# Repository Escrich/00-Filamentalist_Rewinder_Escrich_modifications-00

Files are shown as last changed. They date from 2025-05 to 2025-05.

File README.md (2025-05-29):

# Filamentalist Rewinder Escrich modifications
ERCF Filamentalist rewinder modifications

<p align="left">
testing prototipes
</p>

### Few days ago (20250524), I discovered the Filamentalist  rewinder

Then I decided to print the first prototype and made some changes, after that, I discovered the latest version of Filamentalist rewinder, then I will come back soon with new modifications!

### Modifications has been done on following elements:

- Modified back roller, now has been made as a single part, ussing supports at printing time, I need to have a look to the new ones (V3), in order to adopt the new ones or continue with those rebuilt old ones,
  I made the change to a single part, because the two threaded halves, doesn't rotate too aligned, at least in my prototipe.
- Changed commercial rubber bands by a TPU 3D printed one, with some lines to deliver better grip and improved reel driving.
- Changes on front Rim rollers, because of the use of the new rubber band, I made a modification, converting the old rim in two halves, with a centering ring inside,
  and four heat inserts, mounted from the opposite face as the screws face, using four units of M3x15 screws,
  to have single segure, well centered part, in next days I will make some changes, in order to have the locking screw, to avoid movements relative to the axis.
- Changes in drive roller in order to avoid the use of O-Rings, again a specially designed TPU ring, has been mounted instead the two O-Rings, because of this modification, I did again,
  a two parts drive roller, it closes using 4 units of M2'5x8 screws, and 4 units of M2'5 heat inserted nuts, as I normally do, the nuts are mounteds in the opposite side of the screws side.
- Changes on filament input output part, because as on lots of DYI designs, there is a screw, working as an axle, with a big part of group of parts rotating around it,
  but scrapping the main part with the screw's thread, working as a metal file, then I introduced a piece of 4 mm OD brass pipe, in order to be used as a "bearing", holding inside the moving screw,
  and avoiding the plastic to be scrapped, this is easily understandable looking at the related pictures.

- Added a variant, with locking screw to Rim rollers 20250528.
- Added pictures to Rim rollers with locking screw 20250529.
- Added another back roller model with two parts and a spacer, to be mounted using 688 ball bearings 20250529.

<br>
<p align="left">
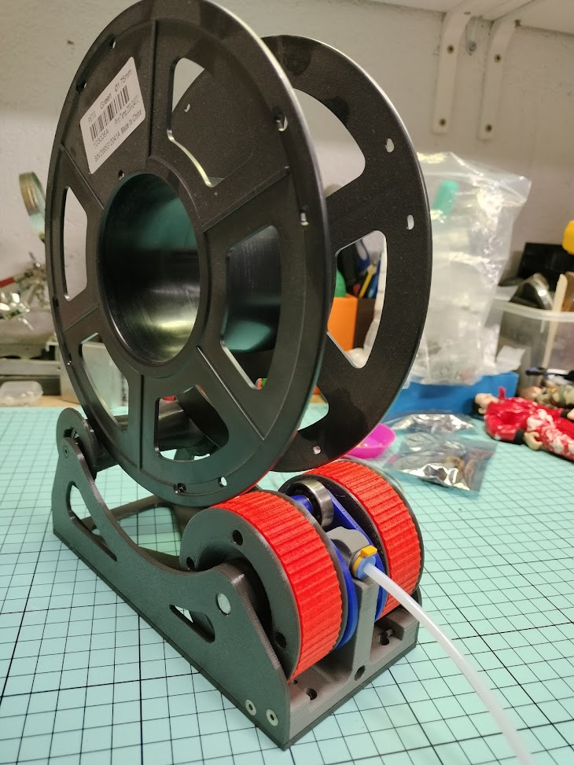
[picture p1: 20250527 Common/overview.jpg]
testing prototipes

</p>
<br>

www.github.com/escrich

https://t.me/escrich

https://www.tiktok.com/@josemescrich

<sub>
20250527 Jose M. Escrich 
</sub>

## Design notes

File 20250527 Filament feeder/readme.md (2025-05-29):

## Metal spacer mounting on it

<p align="left">
Brass pipe
</p>

<p align="left">
Brass pipe
</p>

<p align="left">
Brass pipe
</p>

<p align="left">
Brass pipe
</p>

www.github.com/escrich

<sub> 
20250527 Jose M. Escrich 
</sub>

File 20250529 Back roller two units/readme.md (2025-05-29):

# Two halves Back roller with spacer

<p align="left">
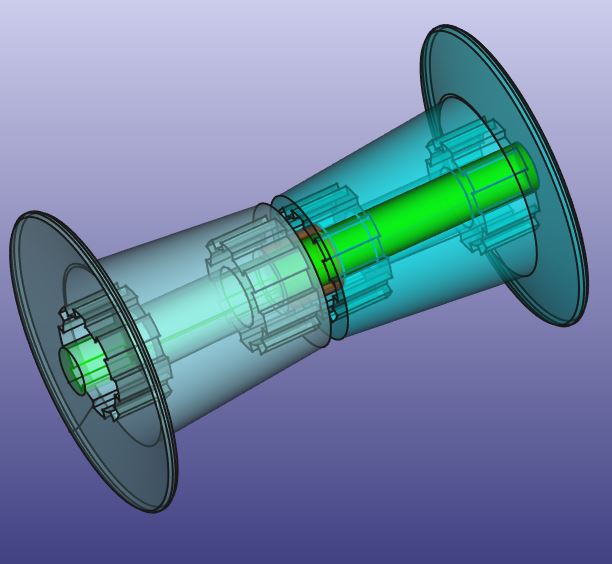
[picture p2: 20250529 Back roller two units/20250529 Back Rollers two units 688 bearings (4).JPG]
Back roller, two pieces and spacer

</p>

### Two halves Back roller with spacer using two units of 688 ball bearings, on each half 

- You need to print two rollers and a single spacer.

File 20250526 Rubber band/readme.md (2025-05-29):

# Rubber band

<p align="left">
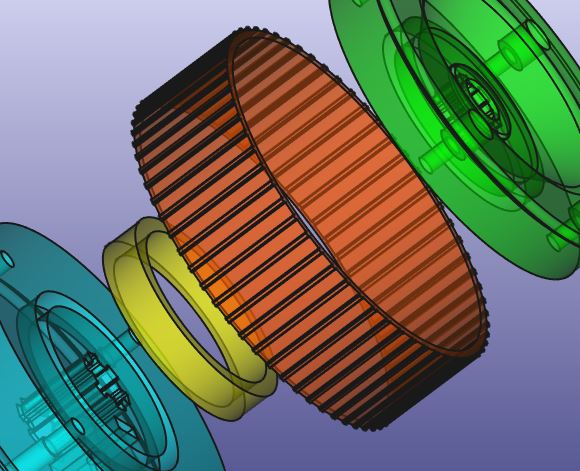
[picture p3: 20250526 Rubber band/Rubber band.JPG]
Rubber band

</p>

### TPU Rubber band, to avoid the commercial ones, and be sourced at home.

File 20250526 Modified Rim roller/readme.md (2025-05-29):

# Modified Rim roller

<p align="left">
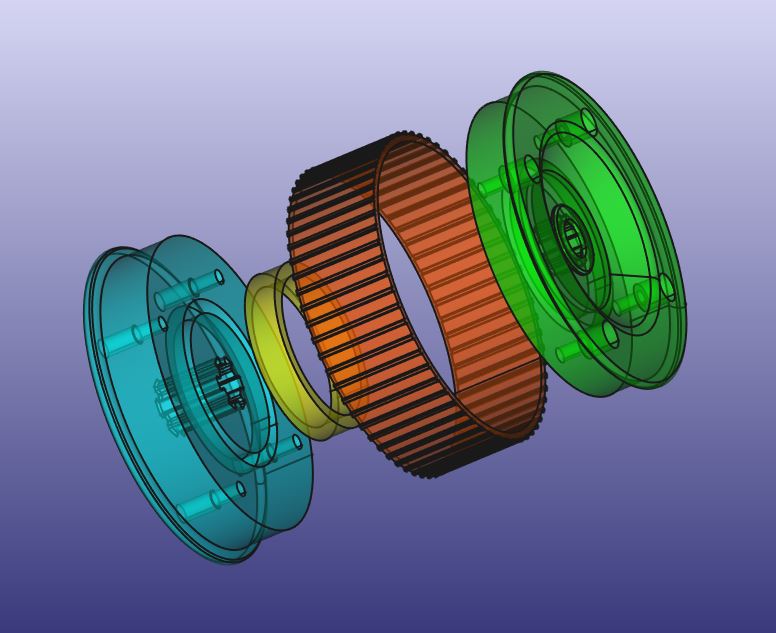
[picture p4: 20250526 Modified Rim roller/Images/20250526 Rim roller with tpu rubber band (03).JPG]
Modified Rim roller

</p>

### Rim roller in two halves to be able to mount a TPU rubber band

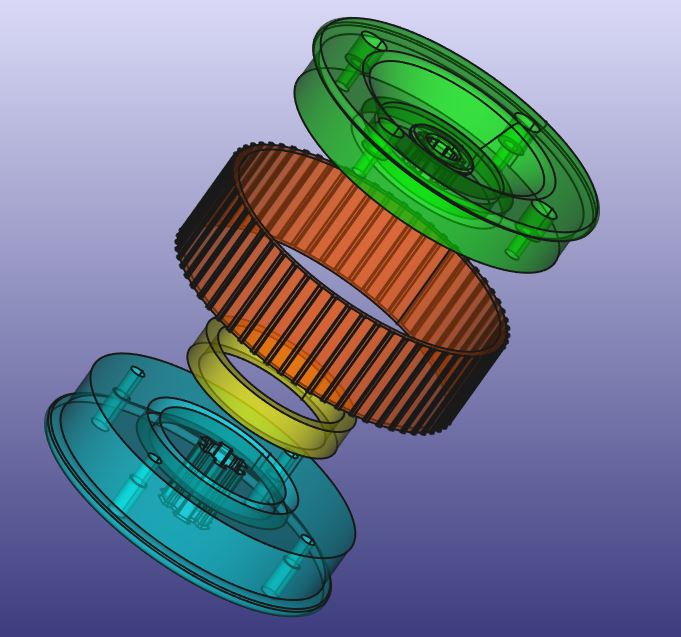
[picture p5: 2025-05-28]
20250526 Modified Rim roller/Images/20250526 Rim roller with tpu rubber band (01).JPG

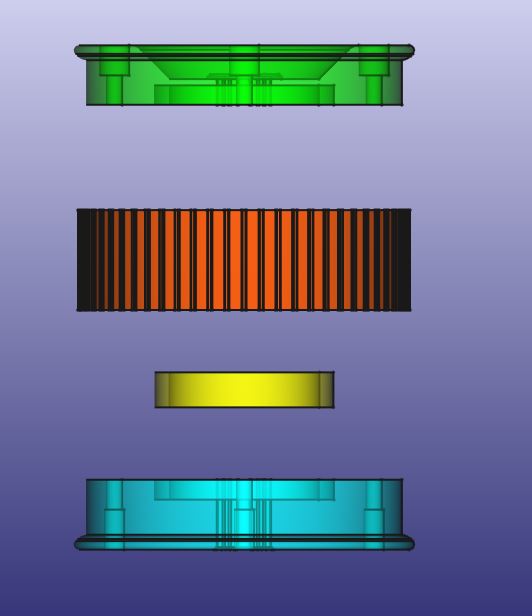
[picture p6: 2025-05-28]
20250526 Modified Rim roller/Images/20250526 Rim roller with tpu rubber band (02).JPG

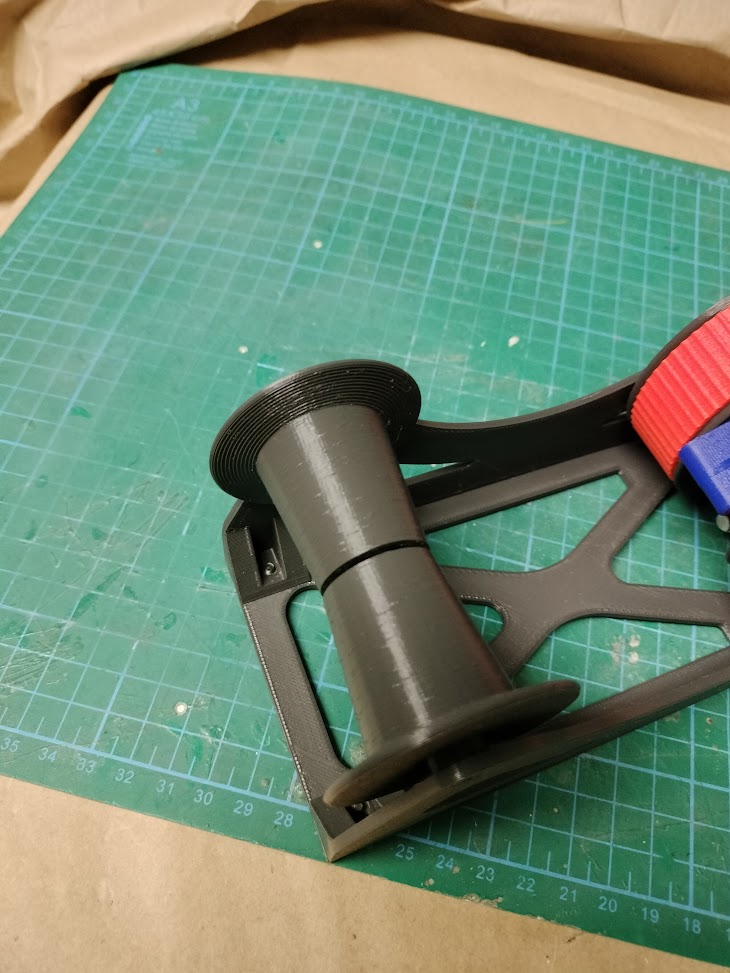
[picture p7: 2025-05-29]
20250529 Back roller two units/20250529 Back Rollers two units 688 bearings (3).JPG

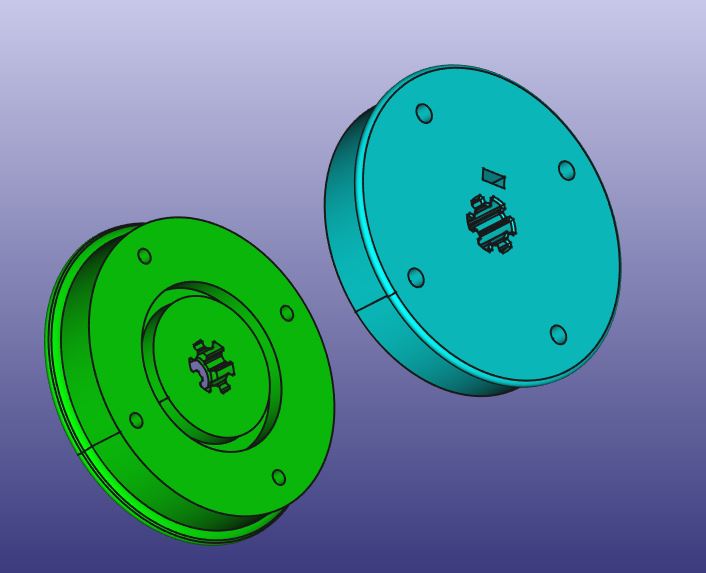
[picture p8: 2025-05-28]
20250526 Modified Rim roller/Rim roller with locking screw/20250528 Half Rim roller with square nut and locking screw (04).JPG

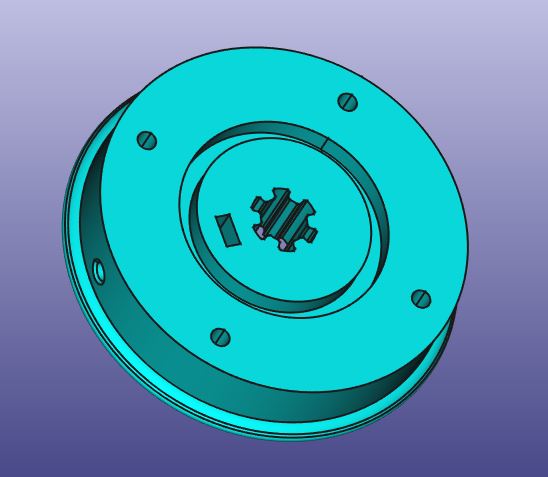
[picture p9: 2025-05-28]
20250526 Modified Rim roller/Rim roller with locking screw/20250528 Half Rim roller with square nut and locking screw (02).JPG

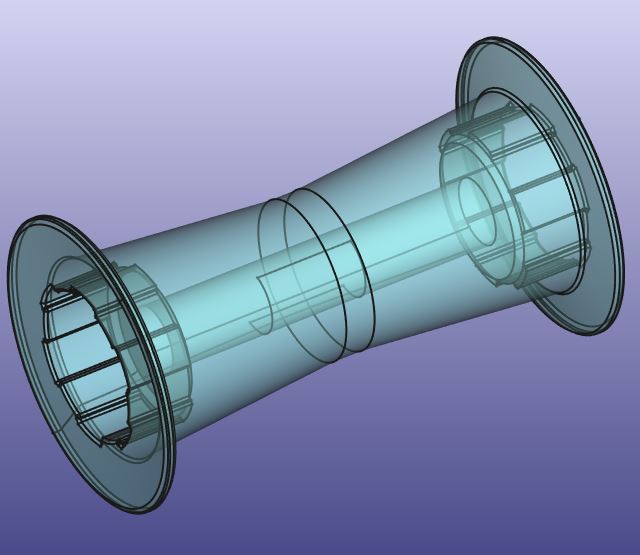
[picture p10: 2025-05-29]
20250526 Modified back roller/Back roller.JPG

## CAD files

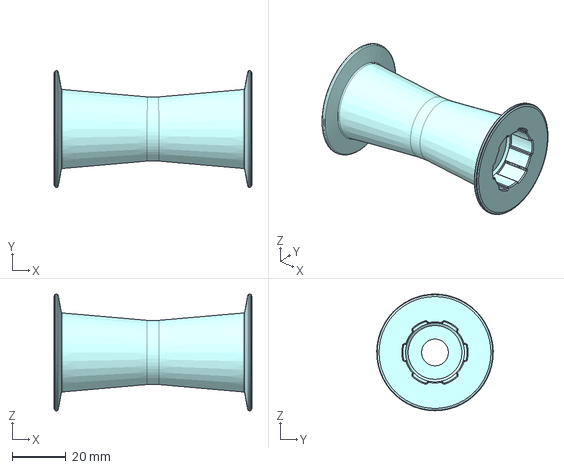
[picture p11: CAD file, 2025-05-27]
20250526 Modified back roller/20250526 Modified back roller-back roller.step
74.0 x 43.6 x 43.6 mm

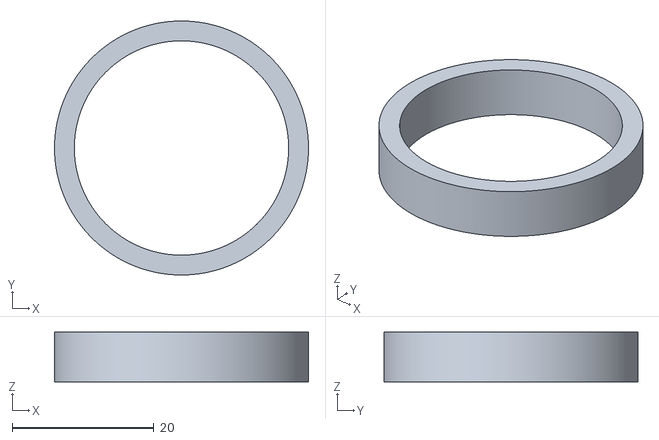
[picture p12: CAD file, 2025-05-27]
20250526 Modified Rim roller/20250526 Modified Rim roller - Centering ring.stl
35.8 x 35.8 x 7.00

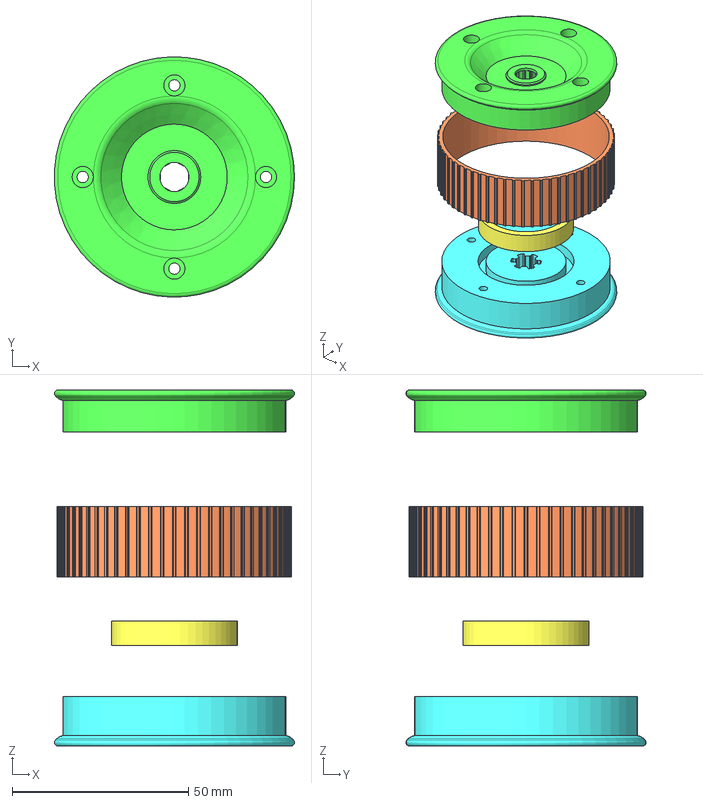
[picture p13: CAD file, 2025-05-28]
20250526 Modified Rim roller/Rim roller with locking screw/20250528 Modified half of rim roller - locking screw and square M3 nut.step
68.1 x 68.1 x 101.0 mm
rubber band
centering ring
nuevo lado rodamiento
nuevo lado central con prisionero

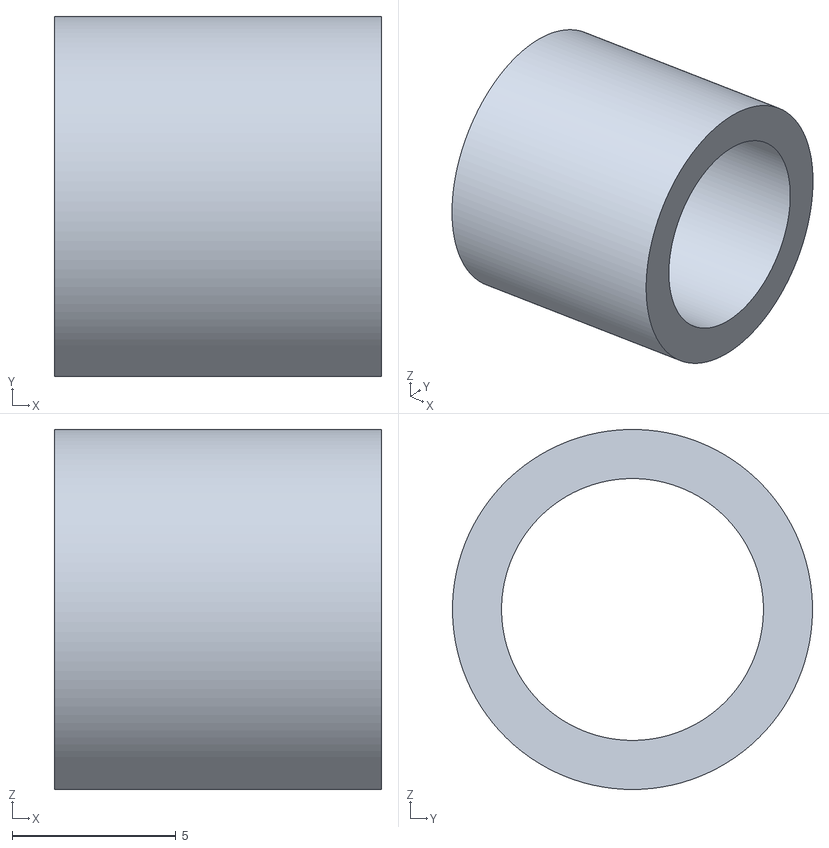
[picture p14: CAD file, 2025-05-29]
20250529 Back roller two units/20250526 Modified back roller-688 spacer.obj
10.0 x 11.0 x 11.0

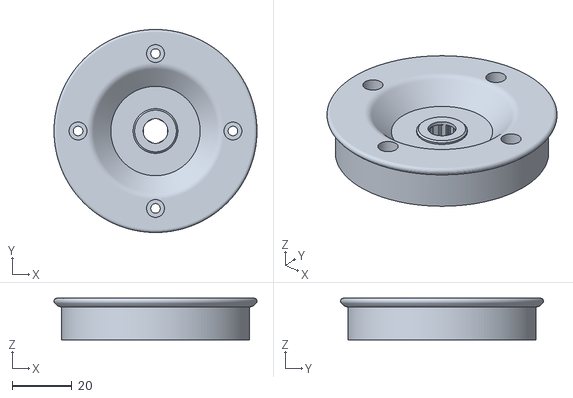
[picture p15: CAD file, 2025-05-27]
20250526 Modified Rim roller/20250526 Modified Rim roller - Bearing side.stl
68.2 x 68.2 x 14.0

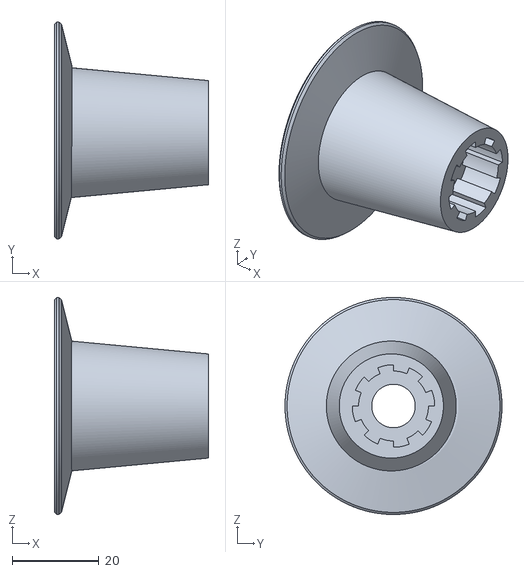
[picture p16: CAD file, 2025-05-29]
20250529 Back roller two units/20250526 Modified back roller-Back half roller.obj
35.5 x 50.0 x 50.0

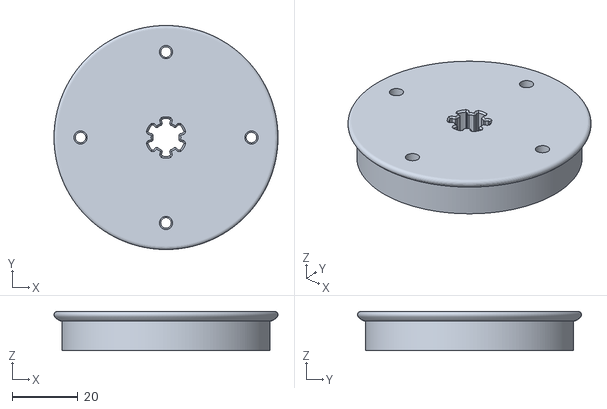
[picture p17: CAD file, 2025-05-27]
20250526 Modified Rim roller/20250526 Modified Rim roller - Center side.stl
68.2 x 68.2 x 11.9

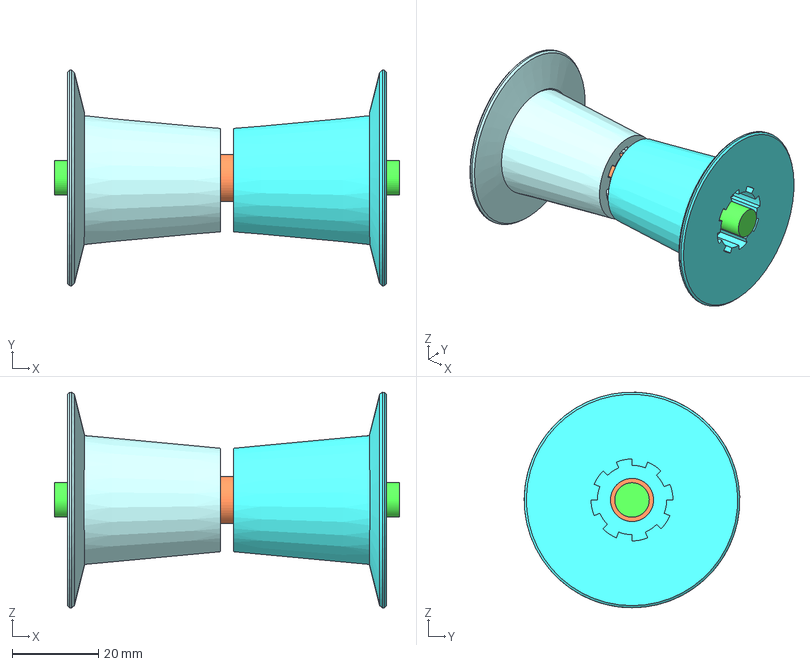
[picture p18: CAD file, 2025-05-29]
20250529 Back roller two units/20250529 Modified back roller-Half roller and 688 spacer.step
80.0 x 50.0 x 50.0 mm
eje trasero x 2
separador 688
back short free roller
back short free roller (Mirror #1)

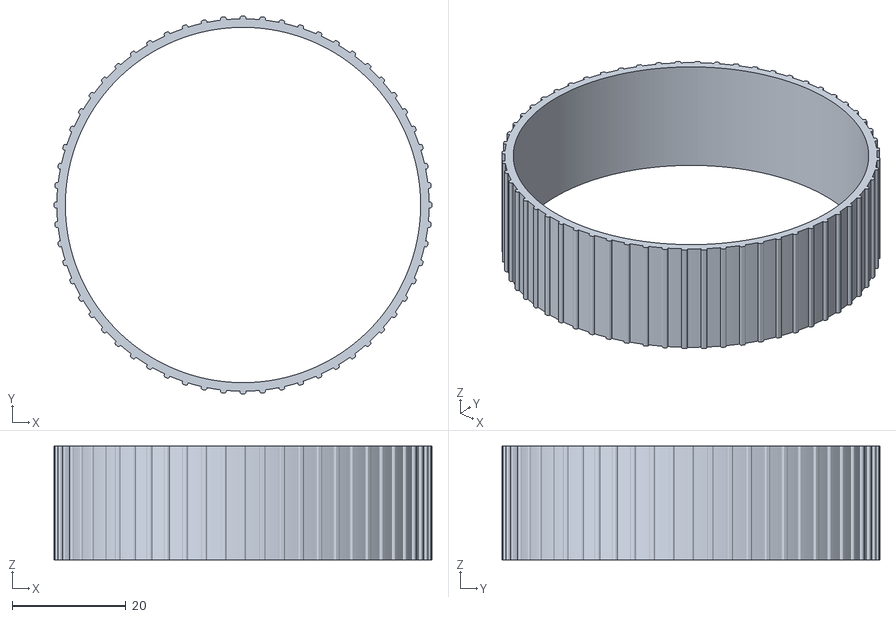
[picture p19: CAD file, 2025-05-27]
20250526 Modified Rim roller/20250526 Modified Rim roller - Rubber band.stl
66.5 x 66.5 x 20.0

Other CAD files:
20250526 Rubber band/20250525 Rubber band.step
20250526 Modified Rim roller/20250526 Modified Rim roller.step
20250526 Modified Rim roller/20250526 Modified Rim roller - Bearing side.obj
20250526 Modified Rim roller/20250526 Modified Rim roller - Center side.obj
20250526 Modified Rim roller/20250526 Modified Rim roller - Centering ring.obj
20250526 Modified Rim roller/20250526 Modified Rim roller - Rubber band.obj
20250526 Modified Rim roller/Rim roller with locking screw/20250528 Modified half of rim roller - locking screw and square M3 nut.stl
20250526 Rubber band/20250525 Rubber band.obj

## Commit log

2025-05-27 First load
    [20250525 Rubber band.obj, 20250525 Rubber band.step, 20250526 Modified Rim roller - Bearing side.stl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]
2025-05-28 added locking screw
    [20250528 Modified half of rim roller - locking screw and square M3 nut.step]
2025-05-28 Mounting instructions
2025-05-28 Locking screws on Rim rollers added
2025-05-28 heat inserts changes
    [20250528 Modified half of rim roller - locking screw and square M3 nut.step]
2025-05-28 Images update
    [20250528 Modified half of rim roller - locking screw and square M3 nut.step, 20250528 Modified half of rim roller - locking screw and square M3 nut.stl]
2025-05-28 Adding file formats
    [20250526 Modified Rim roller - Bearing side.obj, 20250526 Modified Rim roller - Center side.obj]
2025-05-28 screws images
2025-05-29 Double half back roller
    [20250526 Modified back roller-688 spacer.obj, 20250526 Modified back roller-Back half roller.obj, 20250529 Modified back roller-Half roller and 688 spacer.step]
2025-05-29 Create 20250529 Back Rollers two units 688 bearings (4).JPG
2025-05-29 folder movements
    [20250526 Modified back roller-688 spacer.obj, 20250526 Modified back roller-Back half roller.obj, 20250529 Modified back roller-Half roller and 688 spacer.step]
